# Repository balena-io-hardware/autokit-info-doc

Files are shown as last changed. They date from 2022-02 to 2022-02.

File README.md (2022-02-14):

# Hardware Process enabled Repo

You can find documentation for using the hardware process with repos - starting from the creation of repos on our [landr website](https://landr-balena-io-hardware-repo-hardware-process.netlify.app/)

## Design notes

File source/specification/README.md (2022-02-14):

# Writing the `spec.json`

The `spec.json` is the designers way of communicating with balena CI, and the manufacturing lab. This has
- all the necessary information that's missing from the design files
- meta information about the design

**NOTE : If spec.json is missing or misformed, the hardware process will fail to proceed with your Pull Request**

Here's a sample `spec.json` for your PCB projects

```json
{
    "name": "PCB",
    "description": "PCB DESCRIPTION",
    "hwType" : "pcb",
    "manufacture" : [
        {
            "name": "PCB NAME",
            "parameters": {
                "quantity": 1,
                "material" : "MATERIAL",
                "surface-finish": "FINISH"
            }
        }
    ]
}

```

Here's a sample `spec.json` for your 3D projects

```json
{
    "name": "RPi Heatsink",
    "description": "Heatsink",
    "hwType" : "3d",
    "manufacture" : [
        {
            "name": "Heatsink",
            "parameters": {
                "thickness" : "2mm",
                "quantity": 1,
                "material" : "Copper",
                "material-type": "C101",
                "finish" : "Smoothed",
                "details" : "Etched with logo"
            }
        }
    ]
}
```

Once you have populated the `spec.json`, use https://jsonlint.com/ to check if your file is formatted correctly.

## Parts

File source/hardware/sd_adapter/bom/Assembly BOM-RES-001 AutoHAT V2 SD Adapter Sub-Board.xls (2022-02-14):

Comment | Description | Designator | Footprint | Load | Manufacturer | Manufacturer Part No. | Mount | Notes | Quantity | Rating | Supplier | Supplier Part No. | Value | Layer
18pF | 18pF ±5% 100V Ceramic Capacitor C0G, NP0 0603 (1608 Metric) | C1, C2 | 0603C - HD | YES | Samsung Electro-Mechanics America, Inc | CL10C180JC8NNNC | SMT |  | 2.0 | 100V | Digi-Key | 1276-2210-1-ND | 18pF | None
100nF | 0.10µF 16V Ceramic Capacitor X7R 0402 (1005 Metric) 0.039" L x 0.020" W (1.00mm x 0.50mm) | C3, C5, C6, C8, C9, C10, C12, C13, C15, C16, C17, C18, C19, C21 | 0402 | YES | Samsung Electro-Mechanics America, Inc | CL05B104KO5NNNC | SMT |  | 14.0 | 16V | Digi-Key | 1276-1001-1-ND | 100nF | None
1µF | 1µF 10V Ceramic Capacitor X7R 0603 (1608 Metric) 0.063" L x 0.031" W (1.60mm x 0.80mm) | C4 | 0603C - HD | DNP | Samsung Electro-Mechanics America, Inc | CL10B105KP8NNNC | SMT |  | 1.0 | 10V | Digi-Key | 1276-1946-1-ND | 1µF | None
1µF | 1µF 10V Ceramic Capacitor X7R 0603 (1608 Metric) 0.063" L x 0.031" W (1.60mm x 0.80mm) | C7, C14 | 0603C - HD | YES | Samsung Electro-Mechanics America, Inc | CL10B105KP8NNNC | SMT |  | 2.0 | 10V | Digi-Key | 1276-1946-1-ND | 1µF | None
4.7µF | 4.7µF 10V Ceramic Capacitor X5R 0603 (1608 Metric) 0.063" L x 0.031" W (1.60mm x 0.80mm) | C11, C20 | 0603C - HD | YES | Samsung Electro-Mechanics America, Inc | CL10A475KP8NNNC | SMT |  | 2.0 | 10V | Digi-Key | 1276-1044-1-ND | 4.7µF | None
CUS08F30,H3F | Schottky Diode | D1, D2 | USC | YES | Toshiba Semiconductor and Storage | CUS08F30,H3F | SMT |  | 2.0 | 800mA | Digi-Key | CUS08F30H3FCT-ND |  | None
 | Green 571nm LED Indication - Discrete 2V 0603 (1608 Metric) | D3 | 0603LED - HD | YES | Lite-On Inc. | LTST-C190KGKT | SMT |  | 1.0 | 25mA DC | Digi-Key | 160-1435-1-ND | Green LED | None
300mA | 470 Ohm 1 Ferrite Bead 0603 (1608 Metric) 300mA 350 mOhm Max DCR | FB1 | 0603L - HD | YES | Samsung Electro-Mechanics America, Inc | CIM10J471NC | SMT |  | 1.0 | 300mA | Digi-Key | 1276-6380-1-ND | 300mA | None
2A 0.05 DCR | Inductor | FB2 | 0603L - HD | YES | TDK Corporation | MPZ1608S181ATAH0 | SMT |  | 1.0 | 2A 0.05 DCR | Digi-Key | 445-5220-1-ND | 2A 0.05 DCR | None
WE-Communication Connectors 62900416021 | WR-COM USB SMT Type A | J1 | 62900416021 | YES | W¨¹rth Elektronik eiSos GmbH | 62900416021 | SMT |  | 1.0 |  | Digi-Key | 732-3181-ND |  | None
15-91-0080 | Header, 4-Pin, Dual row | P1 | 15-91-0080 | YES | Molex, LLC | 15-91-0080 | SMT |  | 1.0 |  | Digi-Key | WM17458-ND |  | None
Wurth MicroSD |  | P3 | 693071010811 | YES | Wurth | 693071010811 | SMT |  | 1.0 |  | Wurth | 693071010811 | 693071010811 | None
AWP 08-7240-T | 8 Position Rectangular Socket Connector IDC Gold | P5, P6 |  | YES | Assmann WSW Components | AWP 08-7240-T |  |  | 2.0 |  | Digi-Key | AE11246-ND |  | None
1M | RES SMD 1M OHM 5% 1/10W 0603 | R1 | 0603R - HD | YES | Samsung Electro-Mechanics America, Inc | RC1608J105CS | SMT |  | 1.0 | 0.1W | Digi-Key | 1276-5134-1-ND | 1M | None
825R | 825 Ohm ±1% 0.1W, 1/10W Chip Resistor 0603 (1608 Metric) Moisture Resistant Thick Film | R2 | 0603R - HD | DNP | Yageo | RC0603FR-07825RL | SMT |  | 1.0 | 1% 0.1W | Digi-Key | 311-825HRCT-ND | 825R | None
39.2k | 39.2k Ohm ±1% 0.1W, 1/10W Chip Resistor 0603 (1608 Metric) Moisture Resistant Thick Film | R3 | 0603R - HD | DNP | Yageo | RC0603FR-0739K2L | SMT |  | 1.0 | 1% 0.1W | Digi-Key | 311-39.2KHRCT-ND | 39.2k | None
61.9k | 39.2k Ohm ±1% 0.1W, 1/10W Chip Resistor 0603 (1608 Metric) Moisture Resistant Thick Film | R4 | 0603R - HD | YES | Yageo | RC0603FR-0761K9L | SMT |  | 1.0 | 1% 0.1W | Digi-Key | 311-61.9KHRCT-ND | 61.9k | None
12k | 12k Ohm ±1% 0.1W, 1/10W Chip Resistor 0603 (1608 Metric) Moisture Resistant Thick Film | R5 | 0603R - HD | YES | Yageo | RC0603FR-0712KL | SMT |  | 1.0 | 1% 0.1W | Digi-Key | 311-12.0KHRTR-ND | 12k | None
10k | RES SMD 10K OHM 5% 1/10W 0603 | R6, R7, R10, R11, R12, R15 | 0603R - HD, 0603R - HD, 0603R - HD, 0603R - HD, 0603R - HD, 1608[0603] | YES | Samsung Electro-Mechanics America, Inc | RC1608J103CS | SMT |  | 6.0 | 0.1W | Digi-Key | 1276-5086-1-ND | 10k | None
2k | RES SMD 2K OHM 5% 1/10W 0603 | R8, R9 | 0603R - HD | YES | Yageo | RC0603JR-072KL | SMT |  | 2.0 | 0.1W | Digi-Key | 311-2.0KGRCT-ND | 2k | None
0R | RES SMD 0 OHM JUMPER | R13 | 0603R - HD | YES | Samsung Electro-Mechanics America, Inc | RC1608J000CS | SMT |  | 1.0 | 0.1W | Digi-Key | 1276-3510-1-ND | 0R | None
470R | RES SMD 470 OHM 5% 1/10W 0603 | R14 | 0603R - HD | YES | Samsung Electro-Mechanics America, Inc | RC1608J471CS | SMT |  | 1.0 | 0.1W | Digi-Key | 1276-5054-1-ND | 470R | None
TS3A27518ERTWR | IC MUX/DEMUX 6X1 24WQFN | U1 | QFN-24 | YES | Texas Instruments | TS3A27518ERTWR | SMT |  | 1.0 |  | Digi-Key | 296-25415-1-ND |  | None
USB2642-I/ML | IC FLASH MEDIA CTLR USB2 48VQFN | U2 | QFN48 | YES | Microchip Technology | USB2642-I/ML | SMT |  | 1.0 |  | Digi-Key | USB2642-I/ML-ND |  | None
FT24C04A-ULR-T | EEPROM Memory IC 4Kb (512 x 8) I²C 550ns SOT-23-5 | U3 | SOT-23-5 | YES | Fremont Micro Devices USA | FT24C04A-ULR-T | SMT |  | 1.0 |  | Digi-Key | 1219-1066-1-ND |  | None
24MHz | 24MHz ±20ppm Crystal 6pF 150 Ohm -30°C ~ 85°C Surface Mount 4-SMD, No Lead | Y1 | XTAL - 2 x 1.6 | YES | Murata Electronics North America | XRCGB24M000F2P00R0 | SMT |  | 1.0 |  | Digi-Key | 490-9762-1-ND | 24MHz | None

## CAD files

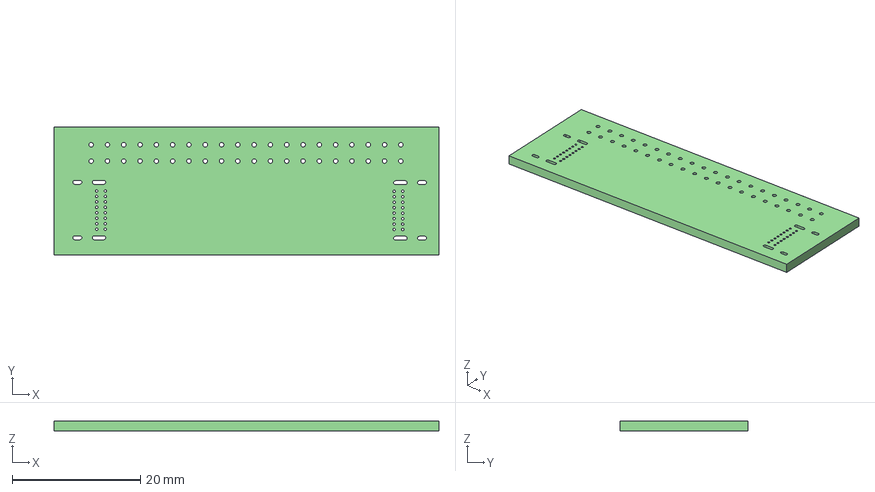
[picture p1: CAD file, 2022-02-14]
source/hardware/autokit-hat/3d/autokit-hat.step
60.0 x 20.0 x 1.60 mm

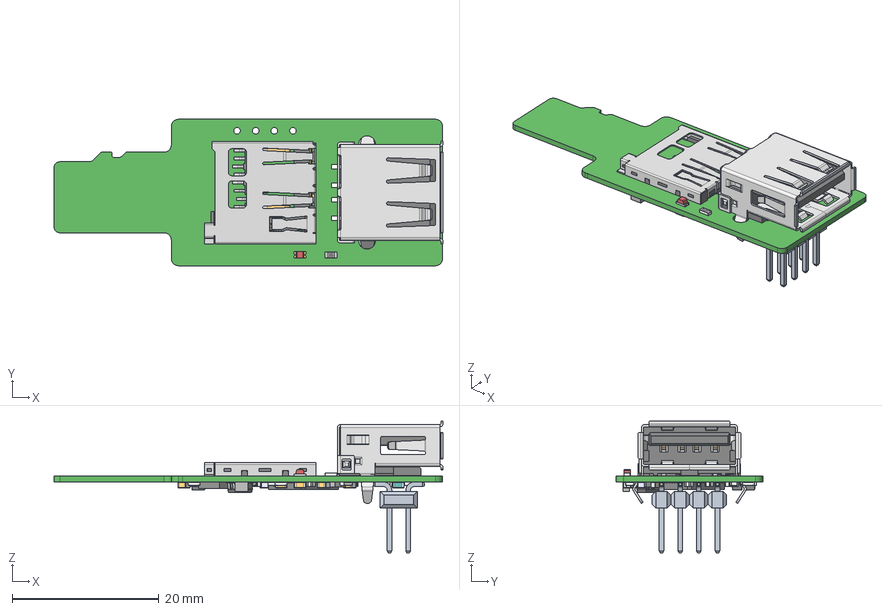
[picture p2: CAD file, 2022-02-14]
source/hardware/sd_adapter/3d/RES-001 AutoHAT V2 SD Adapter Sub-Board - PCB.step
53.0 x 20.0 x 17.9 mm
BoardRES-001_AutoHAT_V2_SD_Adapter_Sub-Board_-_PCB
Open_CASCADE_STEP_translator_6.8_12.1.1 x 2
lead x 4
User_Library-Chip_Capacitor_0603 x 7
Extruded x 45
User_Library-Chip_Inductor x 2
Shielding
Insulator
Pin x 4
693071010811_COULISSEAU
693071010811_CONTACT x 8
693071010811_RESSORT
693071010811_LAME
693071010811_MASSE
693071010811_CACHE
693071010811_AGRAPHE
res0603r x 14
Open_CASCADE_STEP_translator_6.8_2.1
Open_CASCADE_STEP_translator_6.8_2.2.1
Thermal_Shape
Open_CASCADE_STEP_translator_6.8_2.4.1 x 48
User_Library-SOT-23-5_pin_SOT_sot-23-6_1 x 5
User_Library-SOT-23-5_body_sot23-6_1
User_Library-LTST-C190EKT_Pad
User_Library-LTST-C190EKT_Pad005
User_Library-LTST-C190EKT_Pad001
User_Library-LTST-C190EKT_Pad004
User_Library-LTST-C190EKT_Pad003
User_Library-LTST-C190EKT_Lens

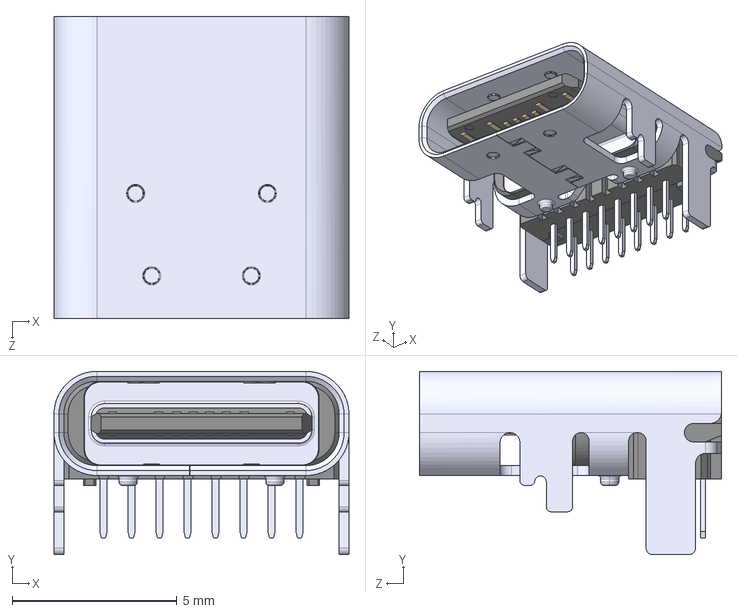
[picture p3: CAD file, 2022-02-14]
source/hardware/SD_Connector/3d/USB4085-GF-A--3DModel-STEP-56544.stp
8.95 x 5.56 x 9.17 mm

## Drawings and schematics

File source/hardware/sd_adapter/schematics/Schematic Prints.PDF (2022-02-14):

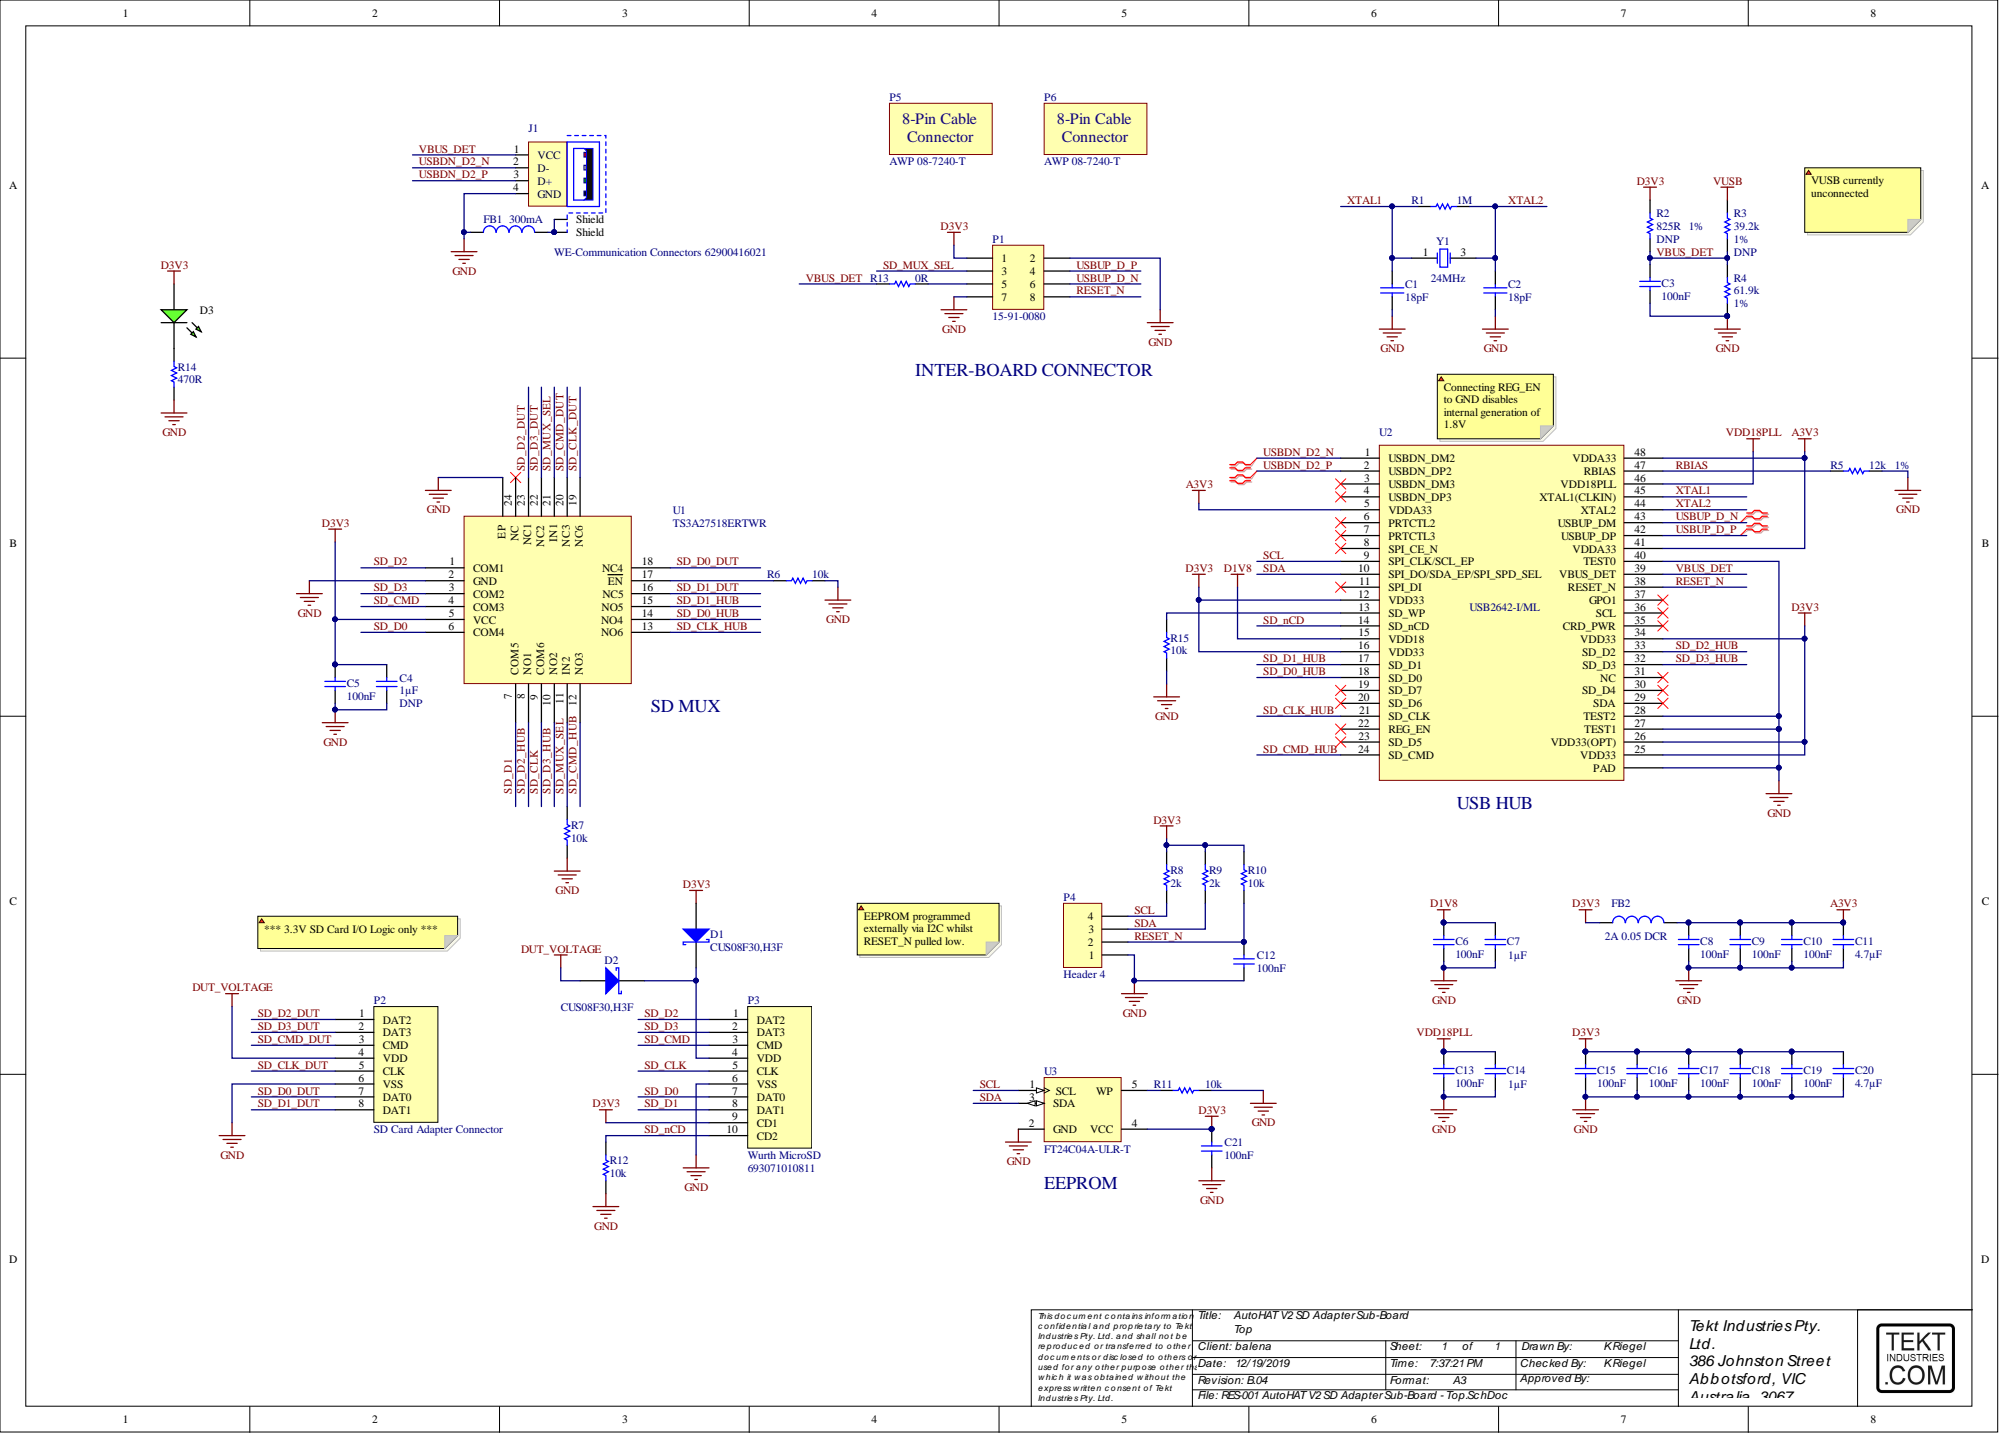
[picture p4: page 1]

USBDN_DP3 4 | XTAL1
VDDA33 5 | XTAL2
PRTCTL2 6 | USBUP_D_N
PRTCTL3 7 | USBUP_D_P

SD_D3 SD_CMD | COM2 3 COM3 4 VCC 5

VDD33 12
SD_WP 13

COM4 6

SD_nCD | | SD_nCD 14 VDD18 15

VDD33 16 | | SD_D2_HUB
SD_D1 17 SD_D0 18 SD_D7 19 | | SD_D3_HUB

*** 3.3V SD Card I/O Logic only ***

SD Card Adapter Connector

This d o c um e nt c o nta ins info rm a tio n c o nfid e ntia l a nd p ro p rie ta ry to Te kt Ind ustrie s Pty. Ltd . a nd sha ll no t b e re p ro d uc e d o r tra nsfe rre d to o the r w hic h it w a s o b ta ine d w itho ut the e xpre ss w ritte n c o nse nt o f Te kt Ind ustrie s Pty. Ltd . | Title: AutoHAT V2 SD Adapter Sub-Board Top | Tekt Industries Pty. Ltd. 386 Johnston Street Abbotsford, VIC Australia, 3067

Client: balena | Sheet: 1 of 1 | Drawn By: K Riegel
Date: 12/19/2019 | Time: 7:37:21 PM | Checked By: K Riegel
Revision: B.04 | Format: A3 | Approved By:

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

RES-001 AutoHAT V2 SD Adapter Sub-Board - Top.SchDoc

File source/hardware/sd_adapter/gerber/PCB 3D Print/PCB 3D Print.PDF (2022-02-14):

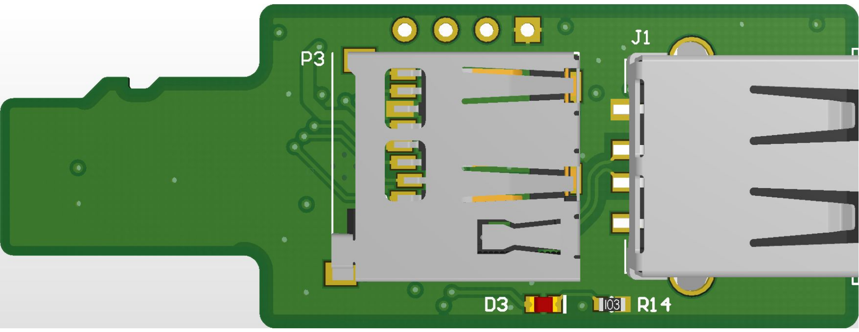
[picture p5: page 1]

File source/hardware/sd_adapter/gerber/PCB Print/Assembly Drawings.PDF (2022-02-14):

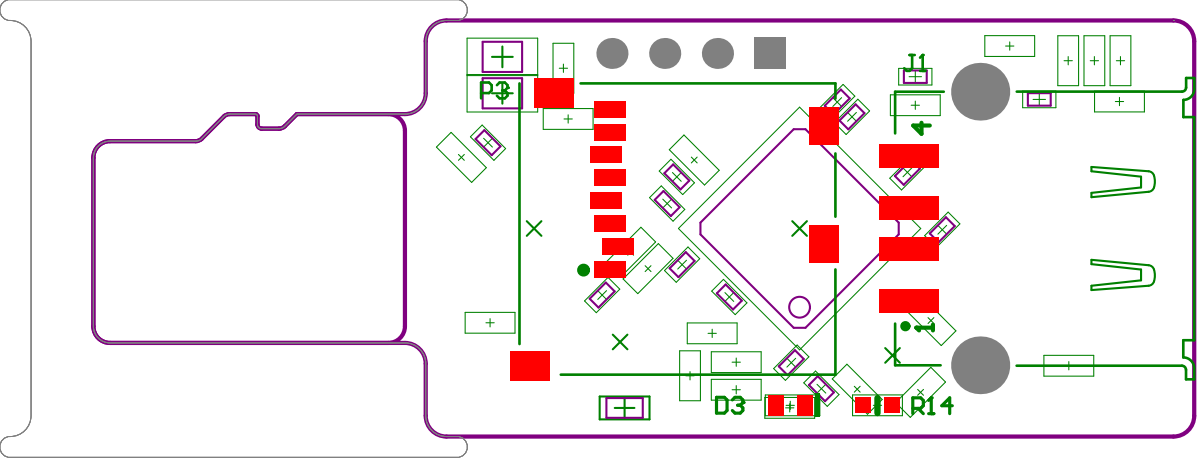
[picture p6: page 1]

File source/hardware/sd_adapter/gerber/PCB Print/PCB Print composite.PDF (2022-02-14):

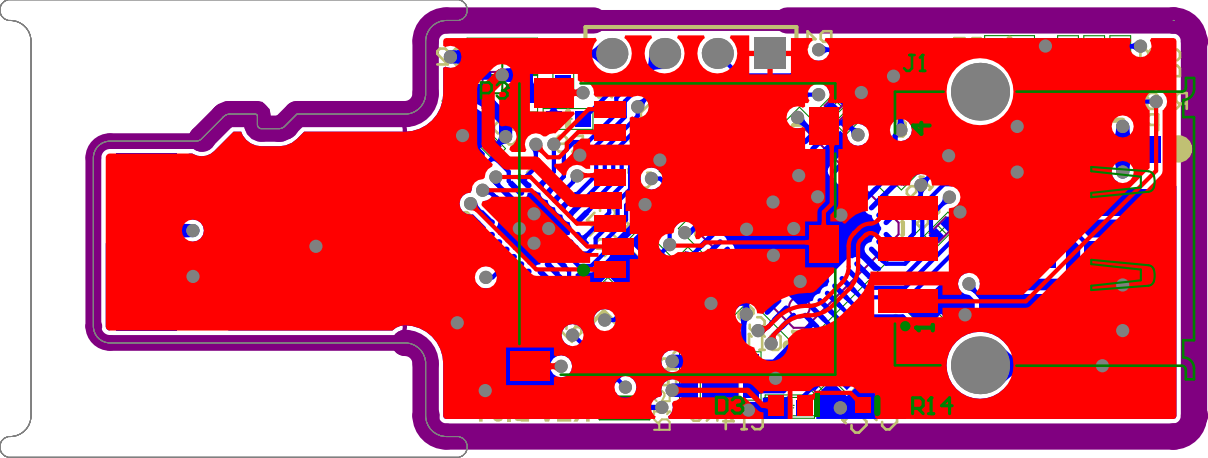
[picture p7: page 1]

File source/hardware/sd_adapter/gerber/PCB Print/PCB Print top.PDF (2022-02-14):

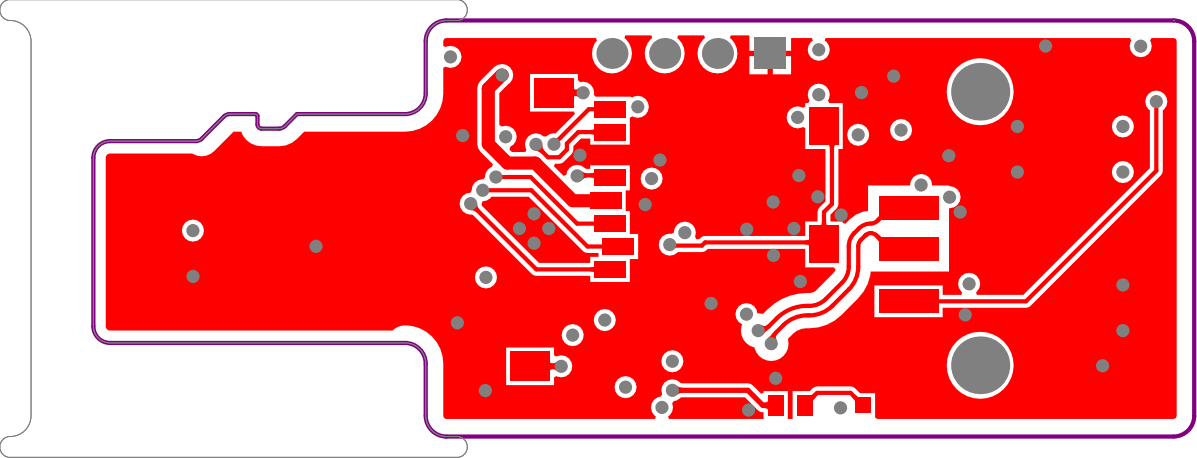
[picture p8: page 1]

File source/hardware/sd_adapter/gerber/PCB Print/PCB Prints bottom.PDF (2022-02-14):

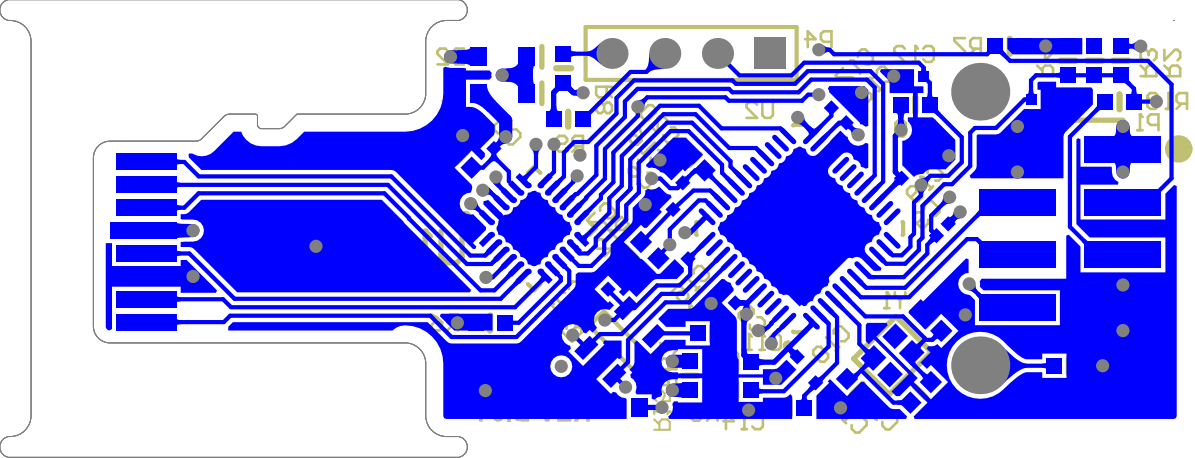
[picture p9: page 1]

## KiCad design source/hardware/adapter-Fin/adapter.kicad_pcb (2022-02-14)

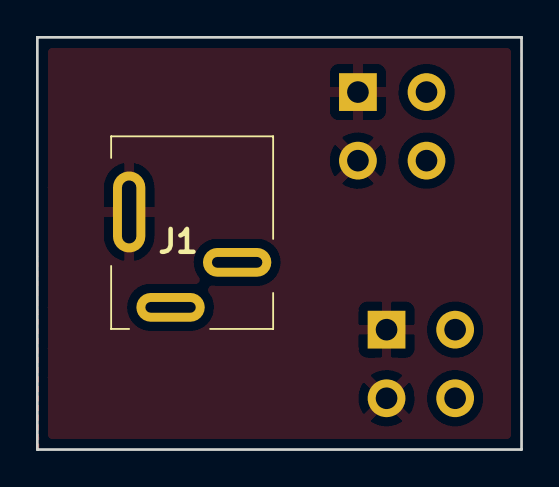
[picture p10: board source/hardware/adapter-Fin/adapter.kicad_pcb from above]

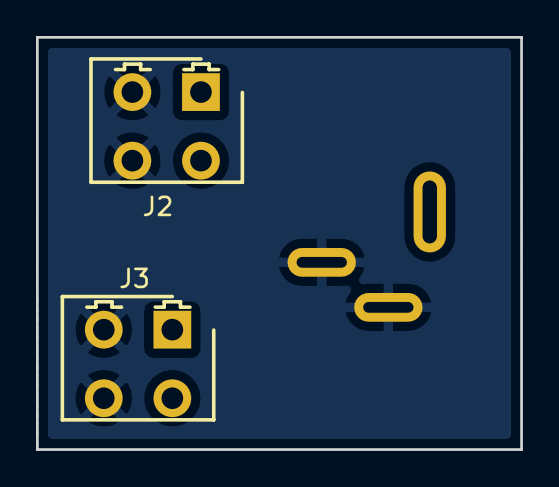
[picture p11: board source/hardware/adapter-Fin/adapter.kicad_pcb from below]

Board: 2 copper layers, 26.9 x 22.9 mm, 3 parts (2 on the bottom side), 2 nets, no tracks yet.

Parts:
J1: Barrel_Jack_Switch; Wurth_694108402002
J2, J3: Phoenix_IMC_1862577; PhoenixContact_IMCV_1777710

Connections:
GND: J1.2, J1.3, J2.3, J2.4, J3.3, J3.4
VCC: J1.1, J2.1, J2.2, J3.1, J3.2

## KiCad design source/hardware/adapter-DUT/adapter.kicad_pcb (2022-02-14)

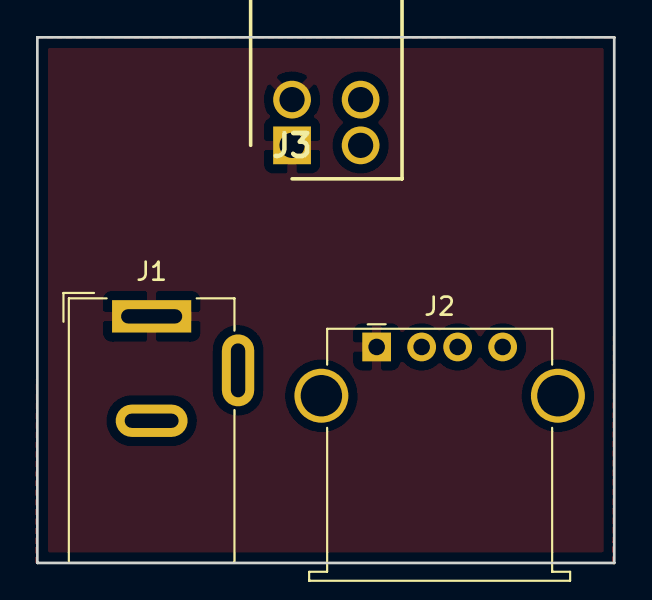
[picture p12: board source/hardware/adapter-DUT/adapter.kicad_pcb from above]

Board: 2 copper layers, 32.0 x 29.2 mm, 3 parts (0 on the bottom side), 2 nets, no tracks yet.

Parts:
J1: Barrel_Jack_Switch; BarrelJack_Wuerth_6941xx301002
J2: USB_A; USB_A_Stewart_SS-52100-001_Horizontal
J3: Phoenix_IMC_1862577; PhoenixContact_IMC_1862577

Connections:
GND: J1.2, J1.3, J2.4, J2.5, J3.3, J3.4
VCC: J1.1, J2.1, J3.1, J3.2

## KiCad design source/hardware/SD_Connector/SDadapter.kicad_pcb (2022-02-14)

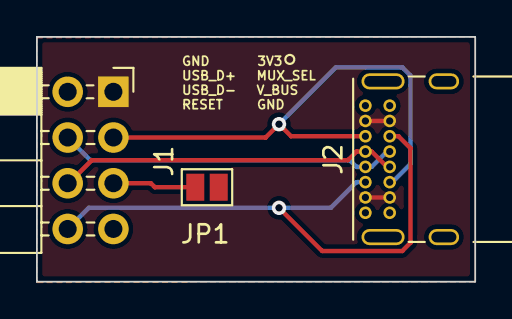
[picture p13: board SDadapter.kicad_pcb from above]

Board: 2 copper layers, 24.3 x 13.6 mm, 3 parts (0 on the bottom side), 7 nets.

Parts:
J1: Conn_02x04_Odd_Even; PinSocket_2x04_P2.54mm_Horizontal
J2: USB_C_Receptacle_USB2.0; USB_C_Receptacle_GCT_USB4085
JP1: SolderJumper_2_Open; SolderJumper-2_P1.3mm_Open_Pad1.0x1.5mm

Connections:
/3V3: J1.1, J2.A4, J2.A9, J2.B4, J2.B9
/RESET_N: J1.8, J2.A5, J2.B5
/SD_MUX_SEL: J1.3, J2.A8, J2.B8
/USB_DN: J1.6, J2.A7, J2.B7
/USB_DP: J1.4, J2.A6, J2.B6
GND: J1.2, J1.7, J2.A1, J2.A12, J2.B1, J2.B12
unnamed: J1.5, JP1.2

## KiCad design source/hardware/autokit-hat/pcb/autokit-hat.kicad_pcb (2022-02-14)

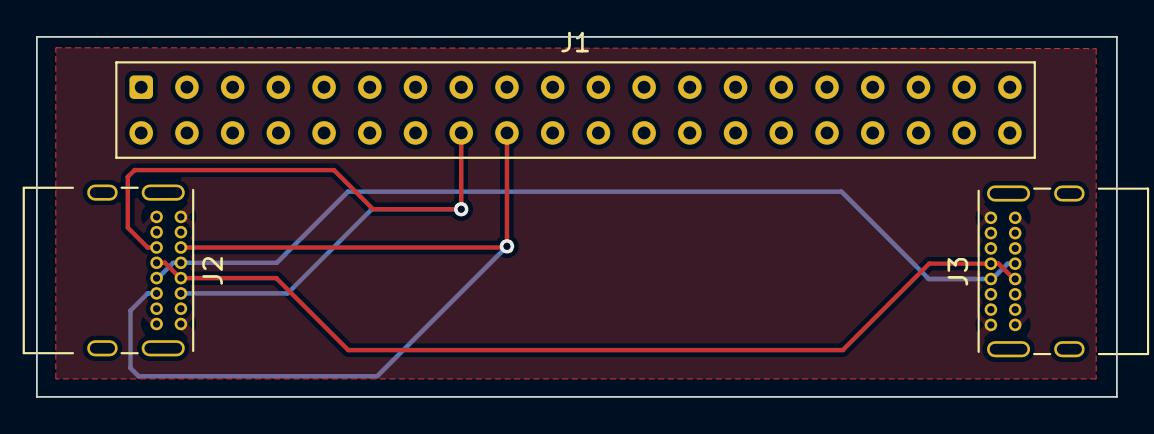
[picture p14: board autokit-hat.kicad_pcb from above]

Board: 2 copper layers, 60.0 x 20.0 mm, 3 parts (0 on the bottom side), 6 nets.

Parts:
J1: Raspberry_Pi_2_3; Samtec_HLE-120-02-xx-DV-TE_2x20_P2.54mm_Horizontal
J2, J3: USB_C_Receptacle_USB2.0; USB_C_Receptacle_GCT_USB4085

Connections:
GND: J2.A1, J2.A12, J2.B1, J2.B12, J3.A1, J3.A12, J3.B1, J3.B12
SD_MUX_RST: J1.18, J2.A5, J2.B5
SD_MUX_SEL: J1.16, J2.A8, J2.B8
USB_DN: J2.A7, J2.B7, J3.A7, J3.B7
USB_PN: J2.A6, J2.B6, J3.A6, J3.B6
VCC: J2.A4, J2.A9, J2.B4, J2.B9, J3.A4, J3.A9, J3.B4, J3.B9

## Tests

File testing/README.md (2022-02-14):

# Testing

In this folder, you have to add atleast one file - `Testing.md`.  Here you will pass instructions to the Prototyping Lab about functional, and other kinds of testing for your prototype. See some examples of this file on [the docs page](https://landr-balena-io-hardware-repo-hardware-process.netlify.app/docs/add-testing-instructions)

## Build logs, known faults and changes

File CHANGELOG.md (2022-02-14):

# Change Log

All notable changes to this project will be documented in this file
automatically by Versionist. DO NOT EDIT THIS FILE MANUALLY!
This project adheres to [Semantic Versioning](http://semver.org/).

# v1.0.0
## (2022-02-14)

* add software files [rcooke-warwick]
* add hardware files [rcooke-warwick]

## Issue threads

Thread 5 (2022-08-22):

Add voltage / current / pwoer  measurement

rcooke-warwick, 2022-08-22:

rcooke-warwick, 2022-08-22:
Some candidates are the "yocto-X" boards:

https://sensorfactory.shop/en/electrical-sensors/55-yocto-volt.html
https://sensorfactory.shop/en/electrical-sensors/50-yocto-amp.html
https://www.yoctopuce.com/EN/products/usb-electrical-sensors/yocto-watt

Pros:
- USB all in one out of the box solution
- HID interface
- AC and DC isolated measurement

Cons:
- expensive
- uncertain about supply chain

rcooke-warwick, 2022-08-22:
Alternatively, we could stitch together "generic" voltage/current sensors with a usb adc, and wrap in a nice enclosure

Pros:
- cheaper
- easier to find alternatives
- stronger supply chain

Cons:
- we have to put some time into developing it
- quality of the sensors?

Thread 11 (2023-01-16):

Remove "hardware" list and point to BoM instead

rcooke-warwick, 2023-01-16:
Point to `autokit-assembly-doc` BoM instead to avoid multiple sources of truth

rcooke-warwick, 2023-01-17:
resolved by https://github.com/balena-io-hardware/autokit-assembly-doc/pull/6

Closed 2023-01-17.

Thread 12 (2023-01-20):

sd mux failures when using "fast" micro sd cards

rcooke-warwick, 2023-01-20:
We've noticed that with some DUT + SD MUX + micro sd card combinations, using a "fast" sd card doesn't work :

- the DUT cannot read from the micro sd card inside the MUX (this happened with some rpi4 based devices
- there may be a failure writing to these cards via the mux

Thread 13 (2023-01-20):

Mechanical issues with the sd mux and certain micro sd card slots

rcooke-warwick, 2023-01-20:
1. Some devices have a spring loaded mechanism that means that the sd mux does not stay inside the DUT micro sd card slot, without some sort of tape.
2. SD mux may stay in the DUT micro sd slot, but when moving the tile, is susceptible to falling out
3. Some devices do not have an accessible micro sd card slot for the mux - an IC blocks it, a connector on the board is positioned in a way that the mux won't fix ( e.g fastenal boards)

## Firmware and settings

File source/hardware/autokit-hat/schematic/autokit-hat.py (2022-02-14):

from pcbflow import *
from skidl import *

rpiHeader = Part("Connector", "Raspberry_Pi_2_3", footprint="Samtec_HLE-120-02-xx-DV-TE_2x20_P2.54mm_Horizontal")
usbHeaderOut = Part("Connector", "USB_C_Receptacle_USB2.0", footprint="USB_C_Receptacle_GCT_USB4085")
usbHeaderIn = Part("Connector", "USB_C_Receptacle_USB2.0", footprint="USB_C_Receptacle_GCT_USB4085")

print(show("Connector", "Raspberry_Pi_2_3"))
print(show("Connector", "USB_C_Receptacle_USB2.0"))


# create the nets
gnd, vcc = Net("GND"), Net("VCC")
sd_mux_sel = Net("SD_MUX_SEL")
sd_mux_rst = Net("SD_MUX_RST")
usb_dn = Net("USB_DN")
usb_pn = Net("USB_PN")


# Make connections GPIO header and USB header
rpiHeader["GPIO23"] & sd_mux_sel & usbHeaderOut["SBU1"] # sd mux sel
rpiHeader["GPIO23"] & sd_mux_sel & usbHeaderOut["SBU2"] # sd mux sel
rpiHeader["GPIO24"] & sd_mux_rst & usbHeaderOut["CC1"] # reset
rpiHeader["GPIO24"] & sd_mux_rst & usbHeaderOut["CC2"] # reset

usbHeaderIn['A6'] & usbHeaderIn['B6'] & usb_pn & usbHeaderOut['A6'] & usbHeaderOut['B6']
usbHeaderIn['A7'] & usbHeaderIn['B7'] & usb_dn & usbHeaderOut['A7'] & usbHeaderOut['B7']
usbHeaderIn['A1'] & gnd & usbHeaderOut['A1']
usbHeaderIn['A12'] & gnd & usbHeaderOut['A12']
usbHeaderIn['B1'] & gnd & usbHeaderOut['B1']
usbHeaderIn['B12'] & gnd & usbHeaderOut['B12']

usbHeaderIn['B4'] & vcc & usbHeaderOut['B4']
usbHeaderIn['A9'] & vcc & usbHeaderOut['A9']
usbHeaderIn['A4'] & vcc & usbHeaderOut['A4']
usbHeaderIn['B9'] & vcc & usbHeaderOut['B9']

#usbHeaderIn['VBUS'] & vcc & usbHeaderOut['VBUS']


generate_netlist()


## Generate board

# brd = Board((65, 30))
# brd.add_outline()
# # fill the top and bottom copper layers and merge nets named "GND"
# #brd.fill_layer("GTL", "GND")
# brd.fill_layer("GBL", "GND")

# rpiHeaderBoard = SkiPart(brd.DC((8, 26)), rpiHeader, side="top")
# usbHeaderBoard = SkiPart(brd.DC((10, 5)), usbHeader, side="top")

# print(usbHeaderBoard)
# #rpiHeaderBoard.pad("SD_MUX_SEL").turtle("r 0 b 20 l 90 f 10").wire(width=0.25)  
# usbHeaderBoard.pad("SD_MUX_RST").w("r 180 f 3 l 90 f 20 l90 f18").wire(width=0.25)     
# usbHeaderBoard.pad("SD_MUX_SEL").w("r 180 f 4 l 90 f 24.2 l90 f20").wire(width=0.25)  

# # save the PCB asset files
# brd.save("mypcb")
